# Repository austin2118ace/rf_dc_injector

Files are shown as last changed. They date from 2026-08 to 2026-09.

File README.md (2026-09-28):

# RF DC Injector

This repository hosts a simple PCB for a RF DC injector/extractor for use in HAM radio applications.

## Brief Description
DC can be co-located on a RF feed line to power remote hardware with only two of these boards. On the injector side, the DC power supply is protected from the RF with a bank of inductors, and the RF power source is isolated from the DC using a capacitor.
On the "extractor" side, the same board is used in the reverse configuration. The antenna is isolated from the DC using the capacitor, and the remote DC power rail is isolated from RF using the inductors.

## Manufacturing
I had several of these boards manufactured at Oshpark but JLCPCB/PCBWay are both valid options. There are two pads for coax connections; I used two lengths of RG316. For the DC power input/output, there is a footprint for a standard DC power jack.
Choose value(s) of capacitance and inductance that make sense for your application.

## Compatability
This project was created using KiCad v10 and includes a custom footprint that you will need to ensure is correctly loaded. 

Good luck and 73!
KQ4TYW

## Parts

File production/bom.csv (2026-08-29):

Designator | Footprint | Quantity | Value | LCSC Part #
C1 | C_Rect_L11.0mm_W3.4mm_P10.00mm_MKT | 1 | 0.1uF
J1 | RG-316-Through-Hole | 1 | RF_NO_DC
J2 | RG-316-Through-Hole | 1 | RF_W_DC
J3 | BarrelJack_Horizontal | 1 | Jack-DC
L1, L2, L3, L4 | L_Axial_L6.6mm_D2.7mm_P10.16mm_Horizontal_Vishay_IM-2 | 4 | 100mH

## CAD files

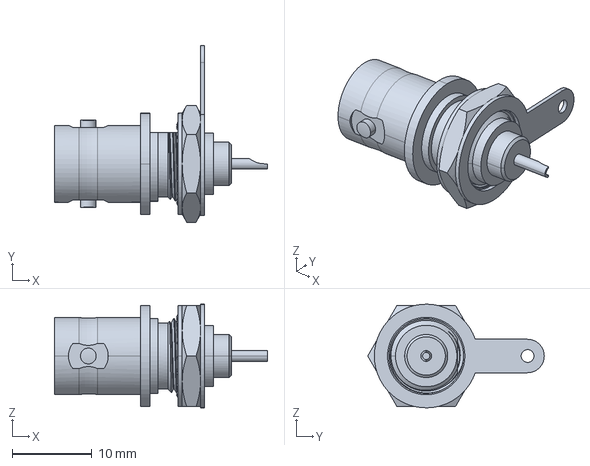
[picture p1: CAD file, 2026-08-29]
31-221-75RFX.stp
26.7 x 22.1 x 13.0 mm

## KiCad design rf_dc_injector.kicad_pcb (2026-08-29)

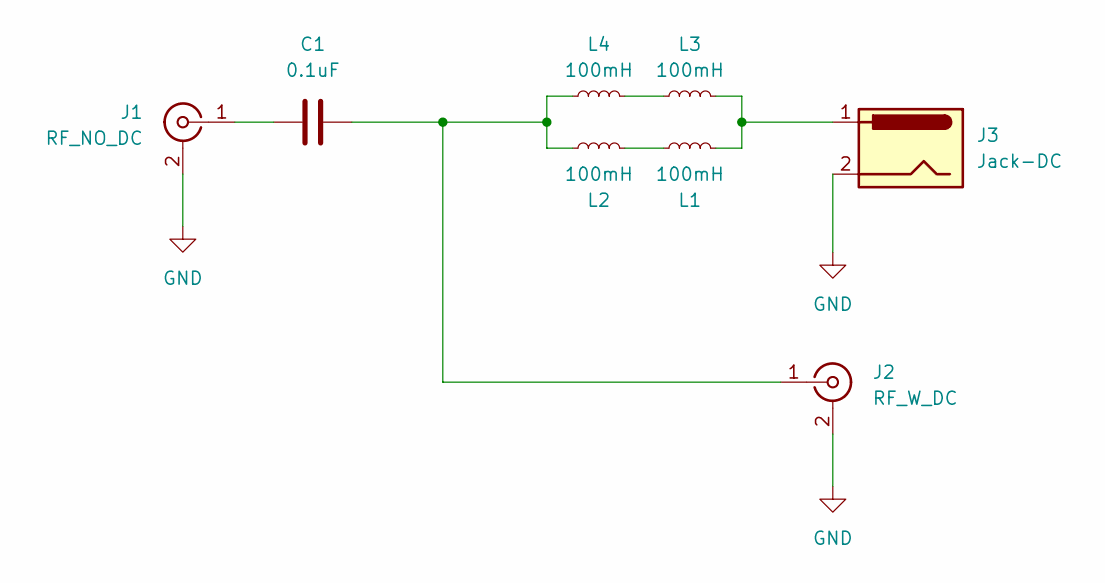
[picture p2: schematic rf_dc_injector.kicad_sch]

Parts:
C1: 0.1uF; C_Rect_L11.0mm_W3.4mm_P10.00mm_MKT
J1: RF_NO_DC; RG-316-Through-Hole
J2: RF_W_DC; RG-316-Through-Hole
J3: Jack-DC; BarrelJack_Horizontal
L1, L2, L3, L4: 100mH; L_Axial_L6.6mm_D2.7mm_P10.16mm_Horizontal_Vishay_IM-2

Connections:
GND: J1.2 (Ext), J2.2 (Ext), J3.2
unnamed: C1.1, J1.1 (In)
unnamed: C1.2, J2.1 (In), L2.1, L4.1
unnamed: J3.1, L1.2, L3.2
unnamed: L3.1, L4.2
unnamed: L1.1, L2.2

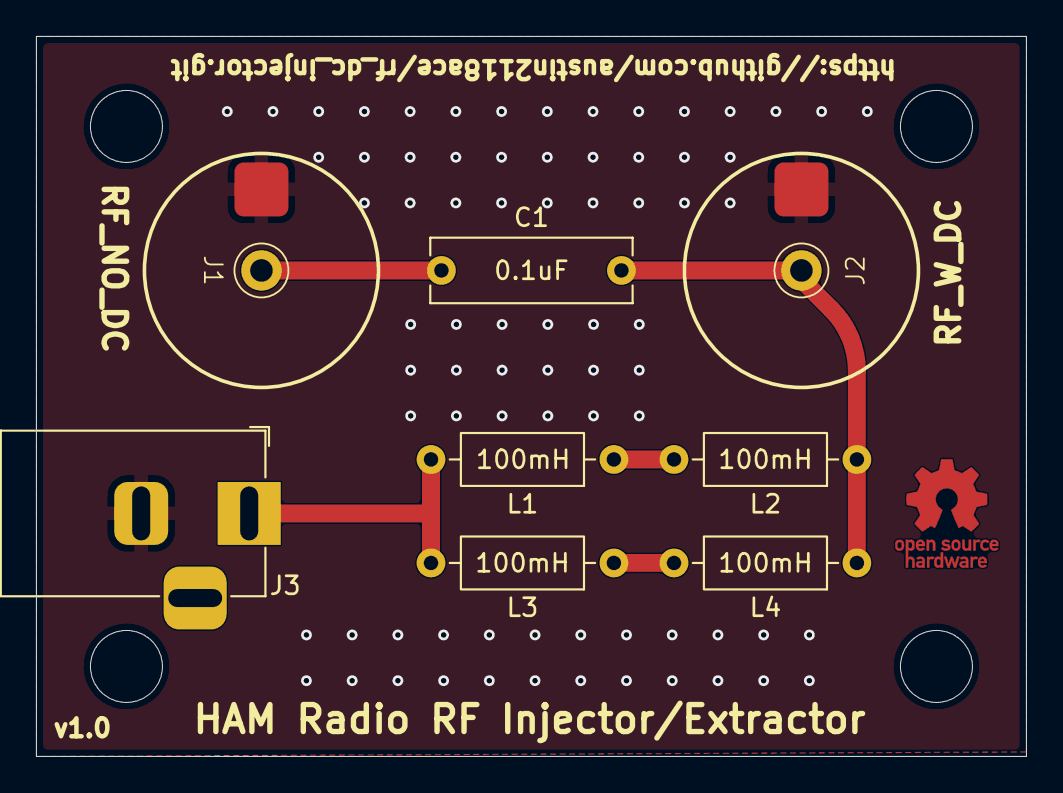
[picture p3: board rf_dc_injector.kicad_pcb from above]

Board: 2 copper layers, 55.0 x 40.0 mm, 8 parts (0 on the bottom side), 6 nets.
